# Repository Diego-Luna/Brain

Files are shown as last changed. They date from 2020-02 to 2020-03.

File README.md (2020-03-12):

# Brain 🧠

Brain(Cerebro) es una placa de desarrollo, que cuenta con un EEG (electroencefalograma) que mediante electrodos medimos la actividad cerebral de 12 Hz - 30 Hz, que corresponde a la concentración, con el objetivo de utilizarlo como una herramienta de aprendizaje en distintas disciplinas que se puede llevar a cualquier parte para aprender mientras te diviertes.
De igual manera se está desarrollando una plataforma para facilitar el uso y el aprendizaje con Brain.

## Desarrollo de placa

Este desarollo es una colaboracion con Electronic cats ([web](https://electroniccats.com))  y MoonMakers ([web](https://moonmakers.org/)) fue creada en la plataforma de Kicad 5.1

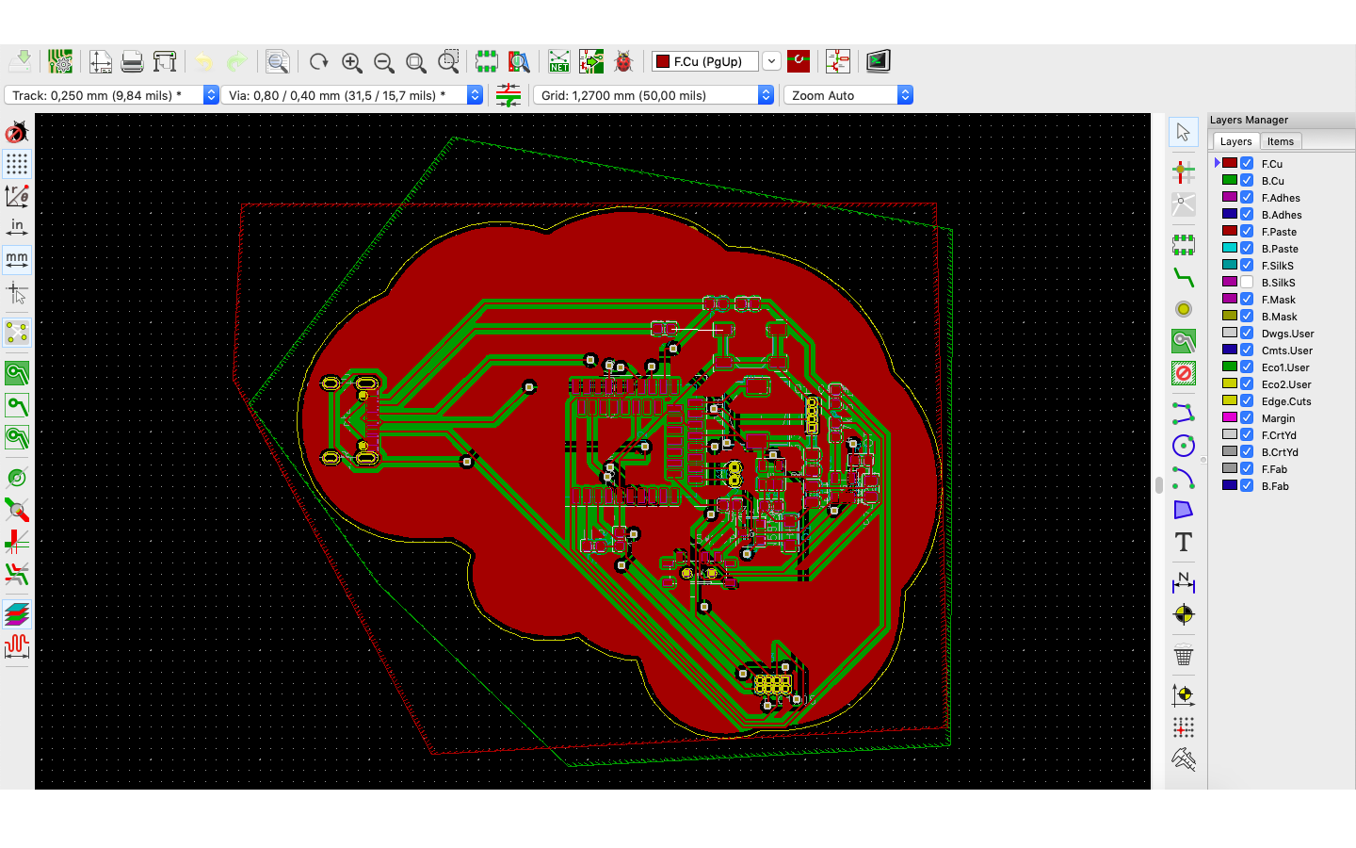
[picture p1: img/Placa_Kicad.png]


Usamos el microcontrolador nrf52840 en la forma E73-2G4M08S1C, está construido alrededor de la CPU ARM® Cortex ™ -M4 de 32 bits, tiene soporte de protocolo para Bluetooth 5, Bluetooth mesh, Thread, Zigbee, 802.15.4, ANT y pilas propietarias de 2.4 GHz. también tienen una resolución de 12 bits en puertos analogicos.

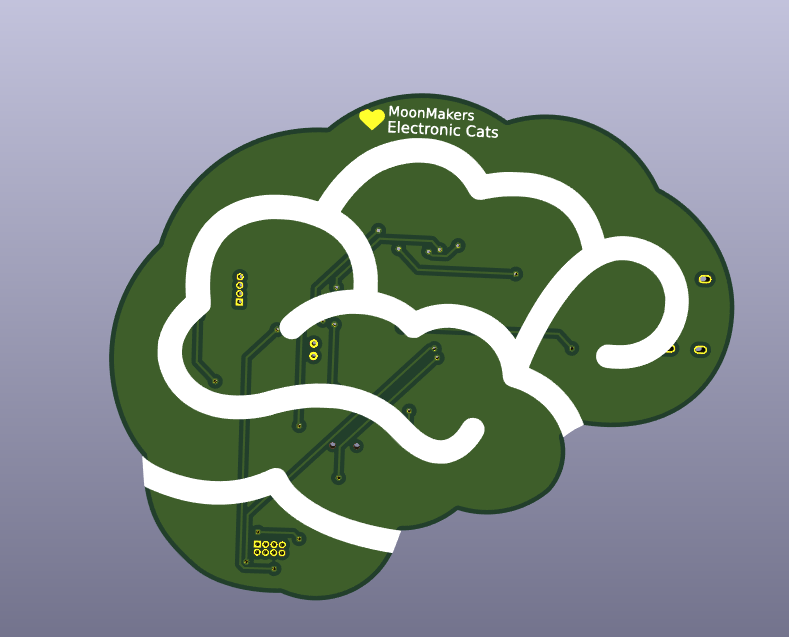
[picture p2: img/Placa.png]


En la parte de los filtros EEG usamos el chip ads1294, cuenta con una resolución de 24 bits por canal, y hasta con 4 canales disponibles que pueden también usarse como un ECG (electrocardiograma)

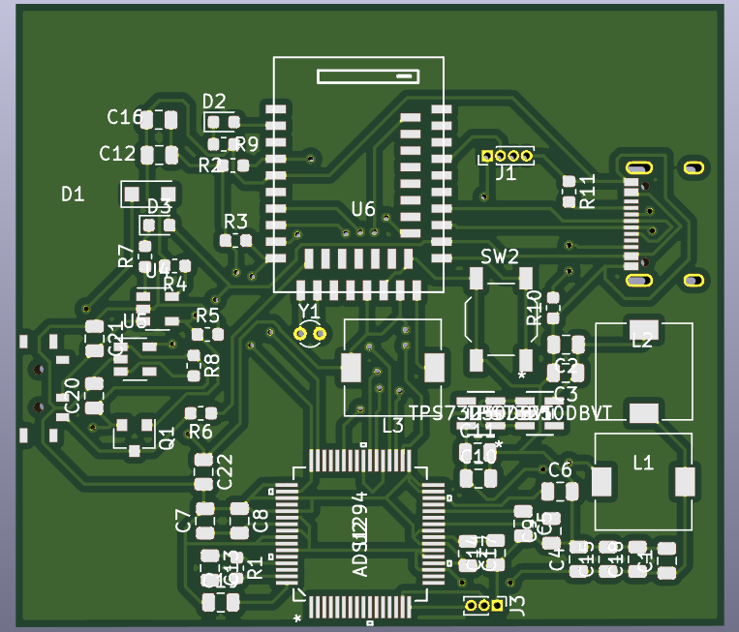
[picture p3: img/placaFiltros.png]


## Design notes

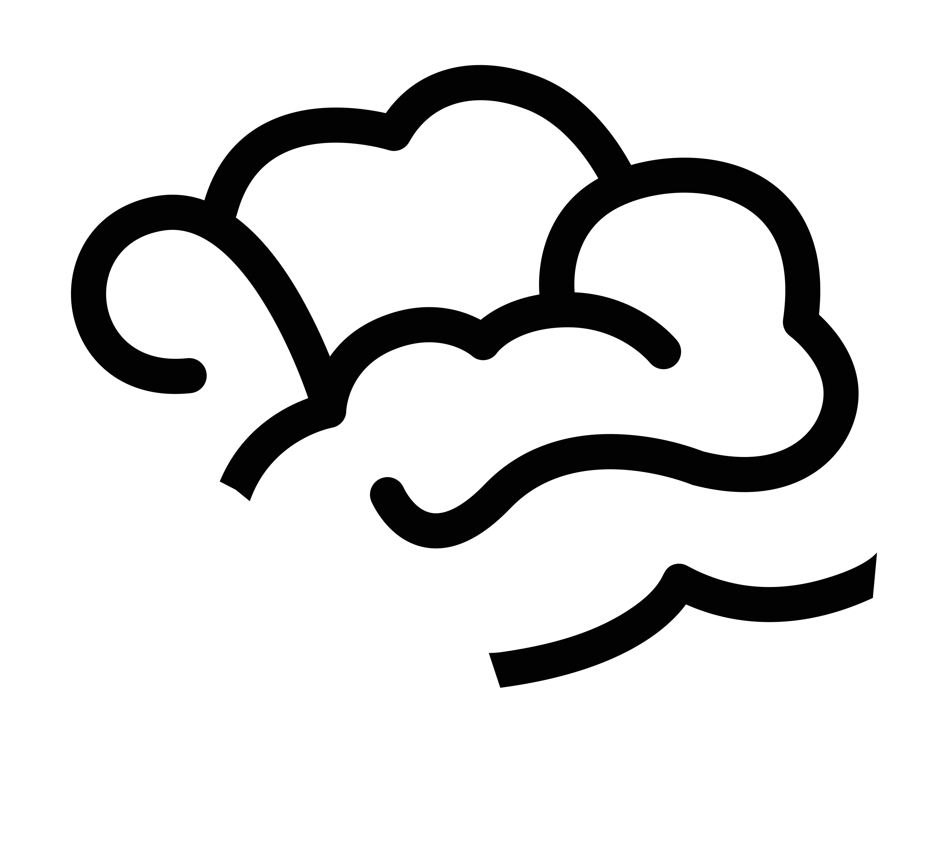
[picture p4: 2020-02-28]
svg-Cerebro/.svg2shenzhen-cache/images/F.SilkS_g44.png

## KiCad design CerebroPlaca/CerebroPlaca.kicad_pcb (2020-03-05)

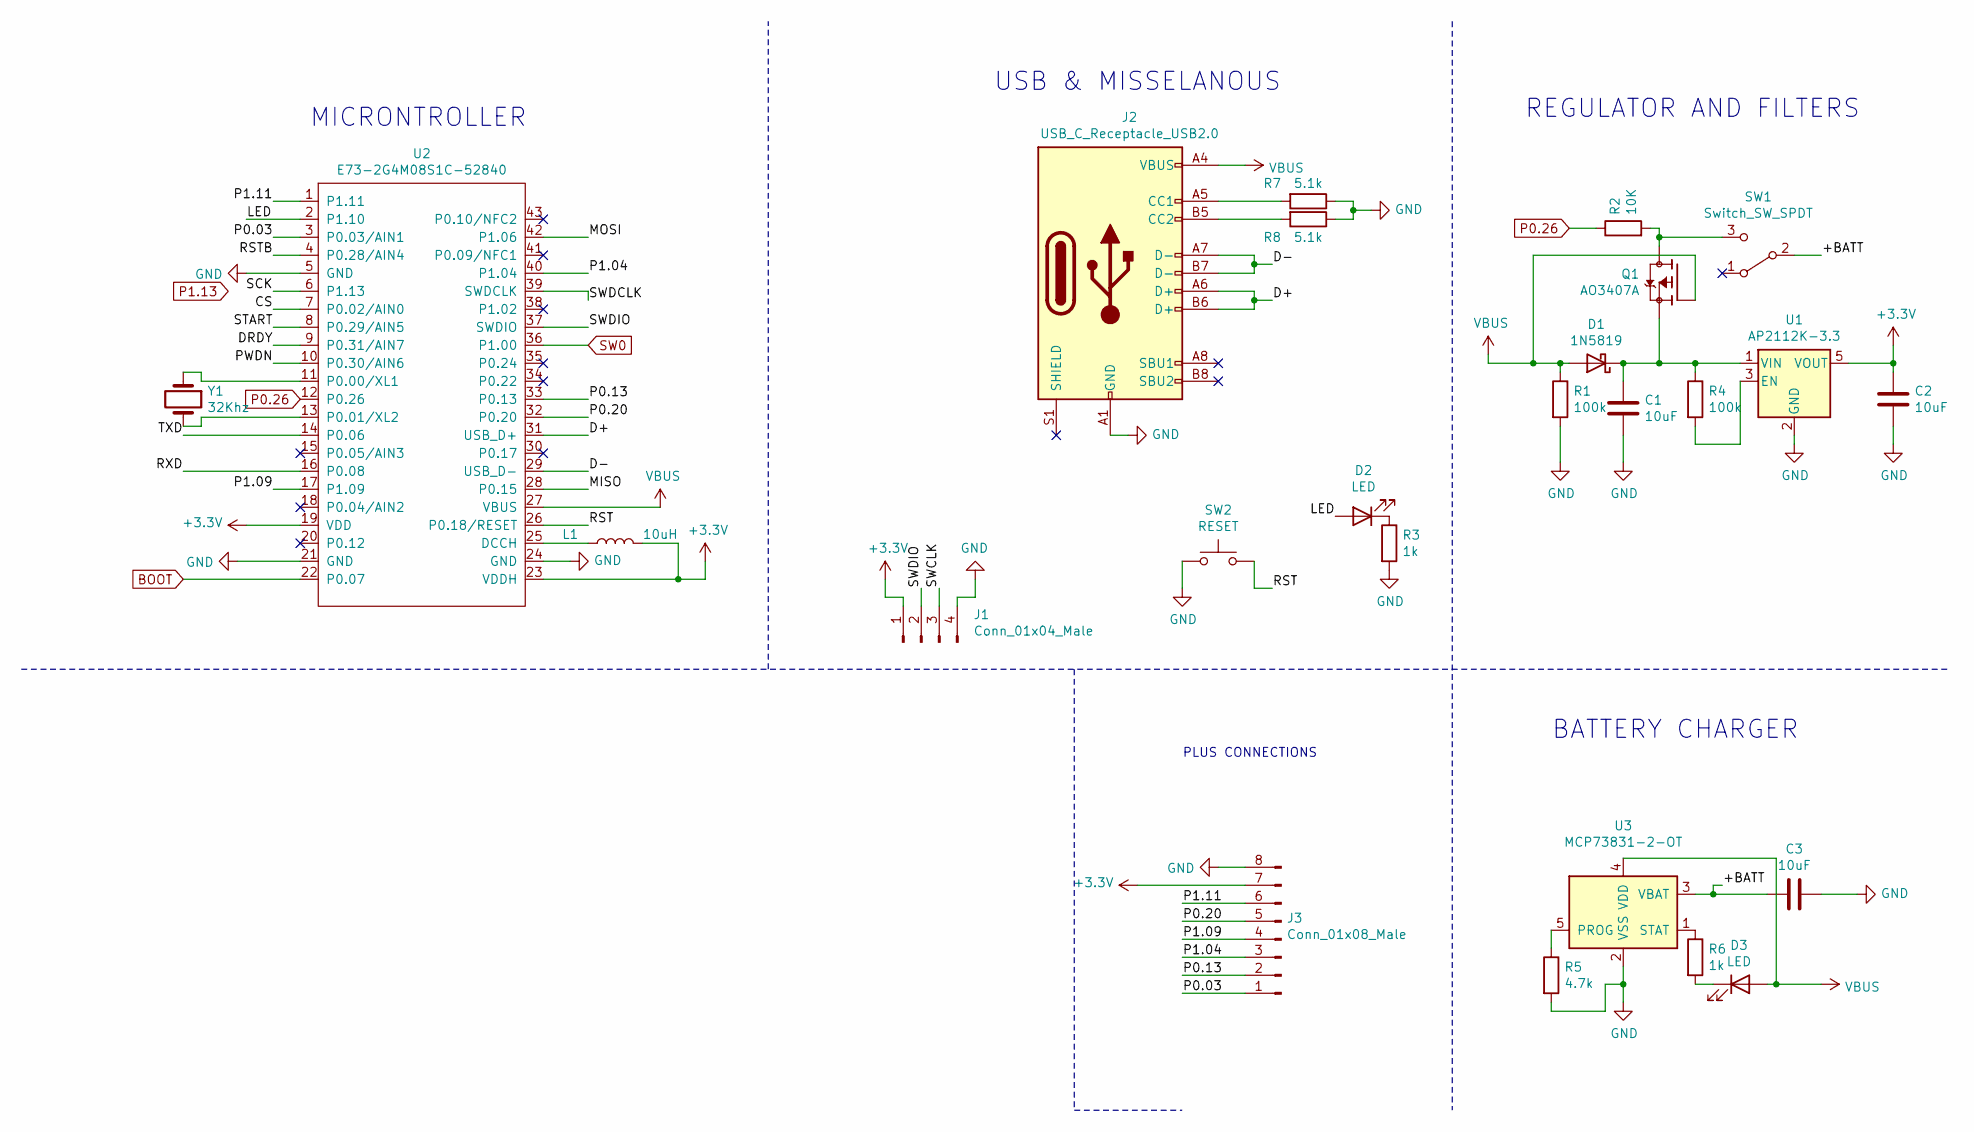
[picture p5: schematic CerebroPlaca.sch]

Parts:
C1, C2, C3: 10uF; C_0805_2012Metric
D1: 1N5819; D_SOD-123F
D2, D3: LED; LED_0603_1608Metric
J1: Conn_01x04_Male; PinHeader_1x04_P1.00mm_Vertical
J2: USB_C_Receptacle_USB2.0; usb_type_c
J3: Conn_01x08_Male; coenctor_8-(4-4)
L1: 10uH; L_7.3x7.3_H3.5
Q1: AO3407A; SOT-23
R1, R4: 100k; R_0603_1608Metric
R2: 10K; R_0603_1608Metric
R3, R6: 1k; R_0603_1608Metric
R5: 4.7k; R_0603_1608Metric
R7, R8: 5.1k; R_0603_1608Metric
SW1: Switch_SW_SPDT; switch_MSK-12C02_smd
SW2: RESET; SW_SPST_TL3342
U1: AP2112K-3.3; SOT-23-5
U2: E73-2G4M08S1C-52840; E73-2G4M08S1C
U3: MCP73831-2-OT; SOT-23-5
Y1: 32Khz; Crystal_Round_D1.0mm_Vertical

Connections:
+3V3: C2.1, J1.1, J3.7, L1.2, U1.5 (VOUT), U2.19 (VDD), U2.23 (VDDH)
/+BATT: C3.2, SW1.2 (B), U3.3 (VBAT)
/CS: U2.7 (P0.02/AIN0)
/D+: J2.A6 (D+), J2.B6 (D+), U2.31 (USB_D+)
/D-: J2.A7 (D-), J2.B7 (D-), U2.29 (USB_D-)
/DRDY: U2.9 (P0.31/AIN7)
/LED: D2.2 (A), U2.2 (P1.10)
/MISO: U2.28 (P0.15)
/MOSI: U2.42 (P1.06)
/P0.03: J3.1, U2.3 (P0.03/AIN1)
/P0.13: J3.2, U2.33 (P0.13)
/P0.20: J3.5, U2.32 (P0.20)
/P1.04: J3.3, U2.40 (P1.04)
/P1.09: J3.4, U2.17 (P1.09)
/P1.11: J3.6, U2.1 (P1.11)
/PWDN: U2.10 (P0.30/AIN6)
/RST: SW2.3 (B), SW2.4 (B), U2.26 (P0.18/RESET)
/RSTB: U2.4 (P0.28/AIN4)
/RXD: U2.16 (P0.08)
/SCK: U2.6 (P1.13)
/START: U2.8 (P0.29/AIN5)
/SWCLK: J1.3
/SWDCLK: U2.39 (SWDCLK)
/SWDIO: J1.2, U2.37 (SWDIO)
/TXD: U2.14 (P0.06)
BOOT: U2.22 (P0.07)
GND: C1.2, C2.2, C3.1, J1.4, J2.A1 (GND), J2.A12 (GND), J2.B1 (GND), J2.B12 (GND), J3.8, R1.2, R3.2, R5.2, R7.1, R8.1, SW2.1 (A), SW2.2 (A), U1.2 (GND), U2.5 (GND), U2.21 (GND), U2.24 (GND), U3.2 (VSS)
unnamed: C1.1, D1.1 (K), Q1.2 (S), R4.1, U1.1 (VIN)
unnamed: D2.1 (K), R3.1
unnamed: D3.1 (K), R6.2
unnamed: J2.A5 (CC1), R7.2
unnamed: J2.B5 (CC2), R8.2
unnamed: L1.1, U2.25 (DCCH)
unnamed: Q1.3 (D), R2.2, SW1.3 (C)
unnamed: R4.2, U1.3 (EN)
unnamed: R5.1, U3.5 (PROG)
unnamed: R6.1, U3.1 (STAT)
unnamed: U2.11 (P0.00/XL1), Y1.1
unnamed: U2.13 (P0.01/XL2), Y1.2
P0.26: R2.1, U2.12 (P0.26)
SW0: U2.36 (P1.00)
VBUS: D1.2 (A), D3.2 (A), J2.A4 (VBUS), J2.A9 (VBUS), J2.B4 (VBUS), J2.B9 (VBUS), Q1.1 (G), R1.1, U2.27 (VBUS), U3.4 (VDD)

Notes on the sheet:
MICRONTROLLER
USB & MISSELANOUS
REGULATOR AND FILTERS
BATTERY CHARGER
PLUS CONNECTIONS

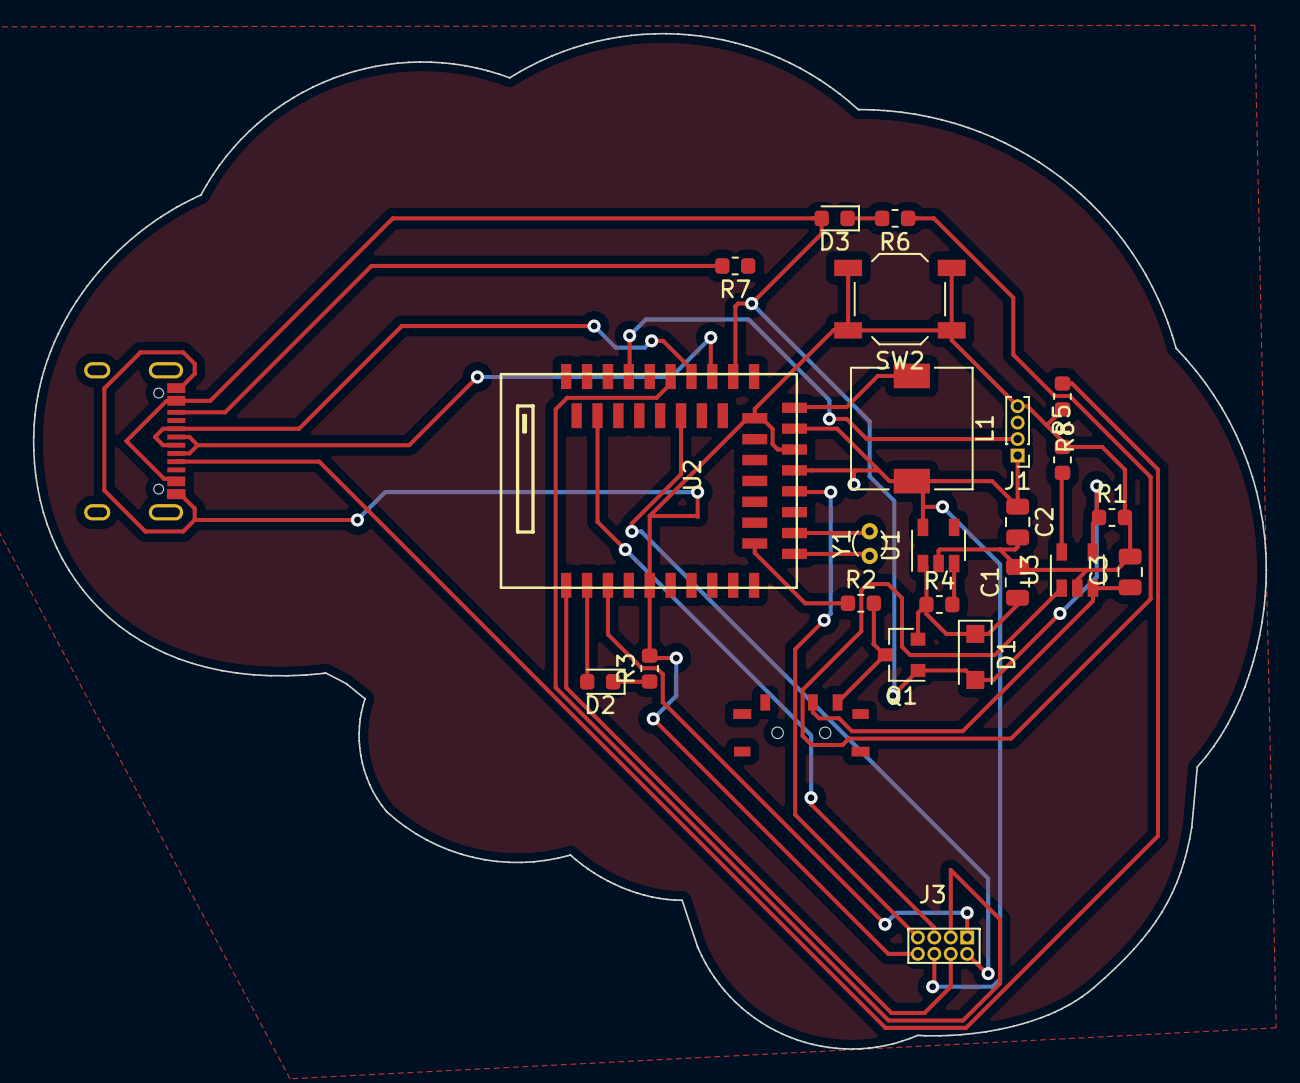
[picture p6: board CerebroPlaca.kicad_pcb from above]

Board: 2 copper layers, 75.0 x 61.8 mm, 26 parts (0 on the bottom side), 27 nets.

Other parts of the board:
Ref**: Val**; CerebroInkscape

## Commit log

2020-02-24 iniciando proyecto
    [CerebroPlaca.kicad_pcb, CerebroPlaca.sch]
2020-02-26 se queda con el USB-C
    [CerebroPlaca.sch]
2020-02-28 Cambio de esquemático en placa cerebro, con prueba de placa de la mima carpeta
    [CerebroPlaca.sch]
2020-03-01 Reconfig schematic
    [CerebroPlaca.sch]
2020-03-01 Fix GND and PWR Reset Resistor
    [CerebroPlaca.sch]
2020-03-03 ajustes en placaCerebro
    [CerebroPlaca.kicad_pcb, CerebroPlaca.sch]
2020-03-03 el esquematico esta casi listo, solo falta la footprin del ads1294
    [CerebroPlaca.sch]
2020-03-04 resize 7.5cm for shezen2kicad
2020-03-05 Tanto esquematico como pcb, preparados
    [CerebroPlaca.sch]
2020-03-05 ajuste de la placa a 7.5 cm de ancho
    [CerebroPlaca.kicad_pcb]
2020-03-05 ajusted de placa
    [CerebroPlaca.kicad_pcb]
